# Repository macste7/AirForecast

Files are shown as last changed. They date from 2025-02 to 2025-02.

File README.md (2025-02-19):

<div align="center">
<h1>AirForecast Open Source Project</h1>
</div>

**AirForecast** was designed to collect and visualize air quality data, as well as predict future values using the [Holt-Winters](https://www.pmorgan.com.au/tutorials/holt-winters-method-and-northam-temperature-data/) model. It utilizes **InfluxDB** for data storage and **Grafana** for visualization. Two **RGB LEDs** provide instant AQI feedback without needing a screen. This project was inspired by the increasing frequency of wildfires worldwide. **AirForecast** helps users stay informed about air quality and potential health risks.

## 🚀 Project Features  
- **2 RGB LEDs** – Instant AQI (PM2.5) visualization  
- **Grafana** – Interactive air quality data visualization  
- **InfluxDB** – Stores data for up to **30 days**  
- **Holt-Winters Model** – Predicts future air quality trends  
- **Environmental Sensors** – Measures **PM1.0, PM2.5, PM10, temperature, humidity, and pressure**  

## 📊 **Grafana Dashboard Output**  
<div align="center">
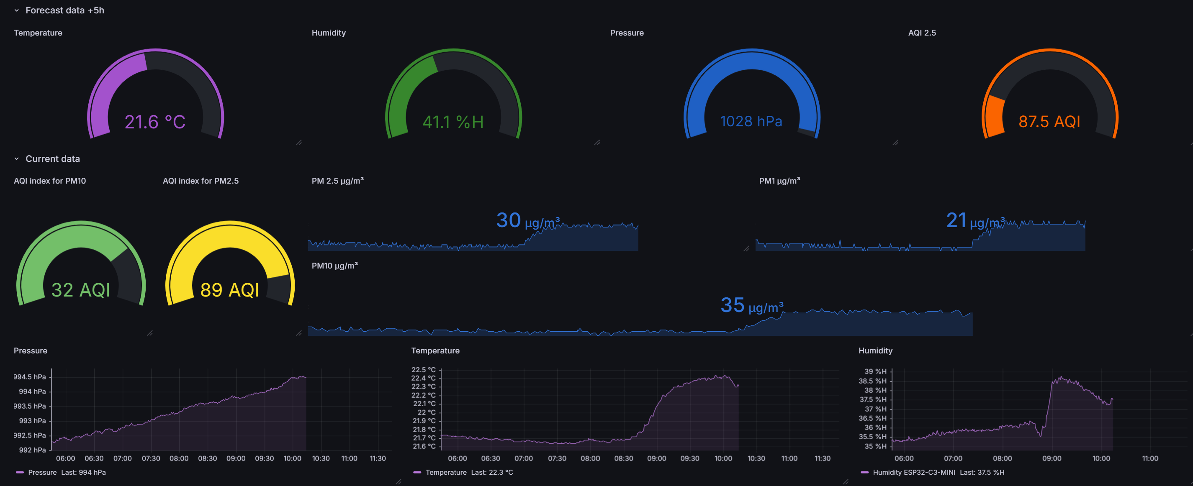
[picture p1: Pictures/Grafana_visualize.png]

</div>

## **AirForecast device**  
<div align="center">
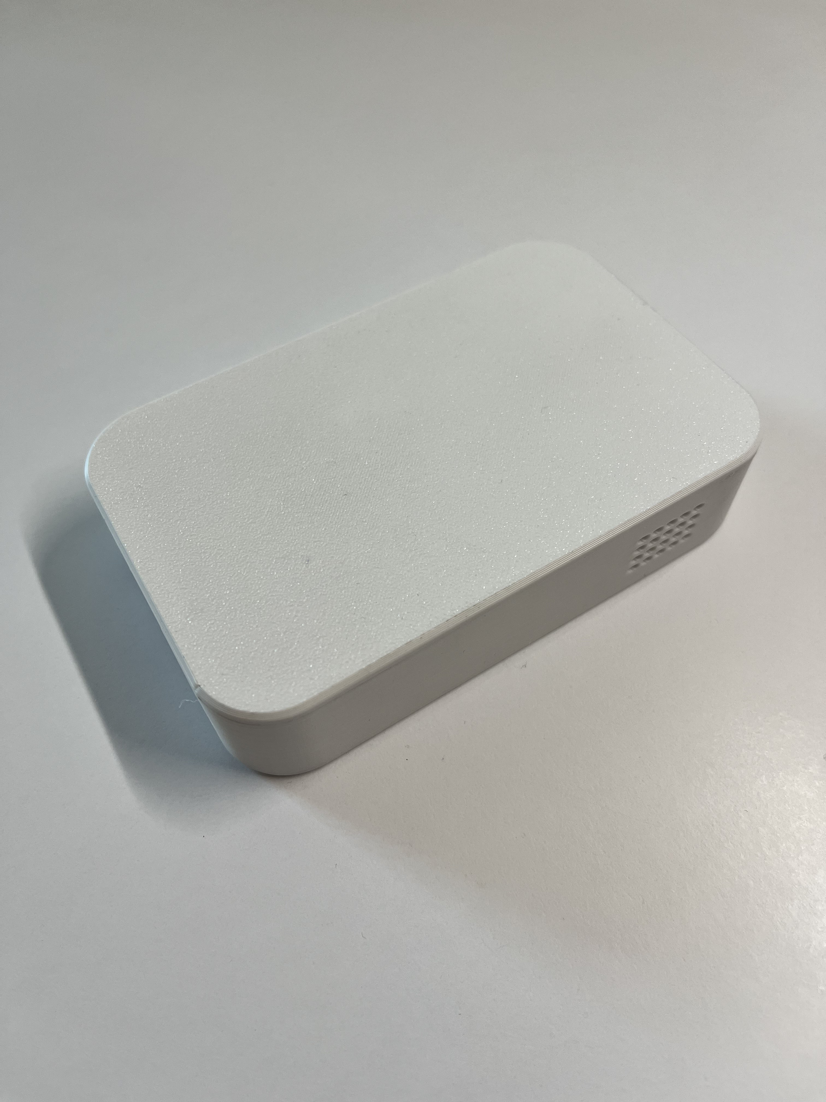
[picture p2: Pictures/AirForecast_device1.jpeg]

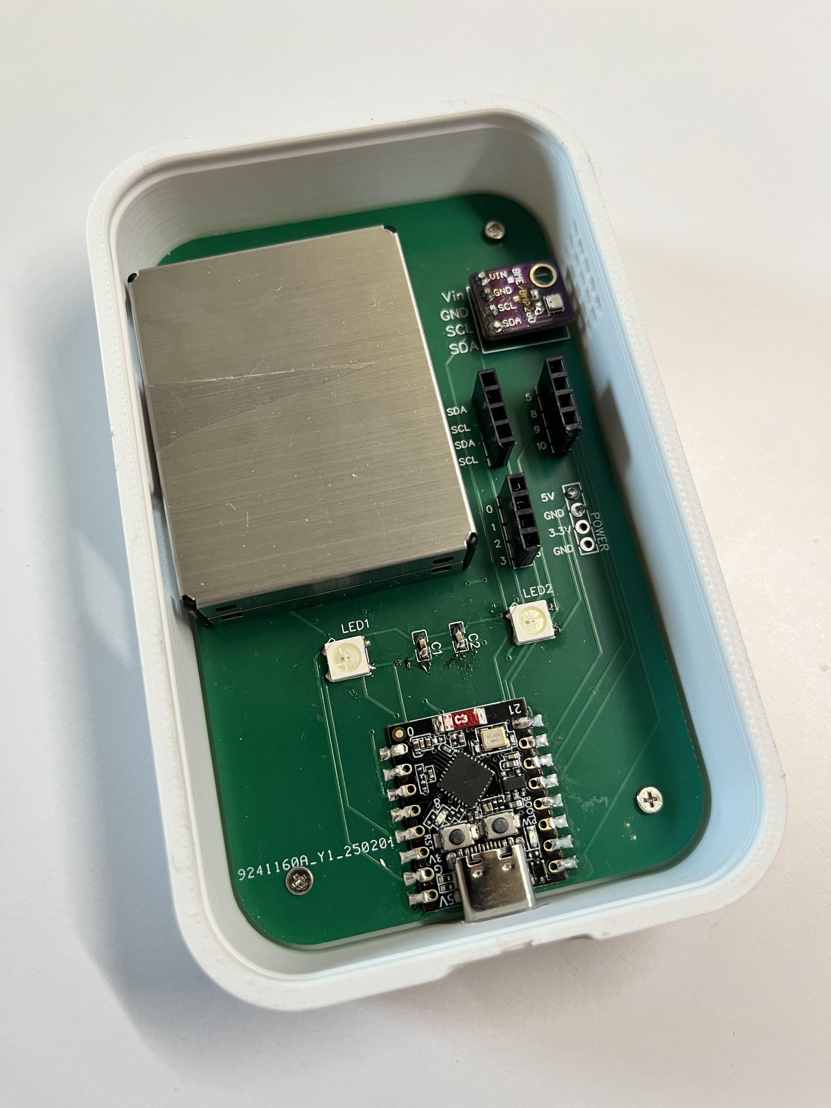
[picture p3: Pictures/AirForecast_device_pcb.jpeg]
  
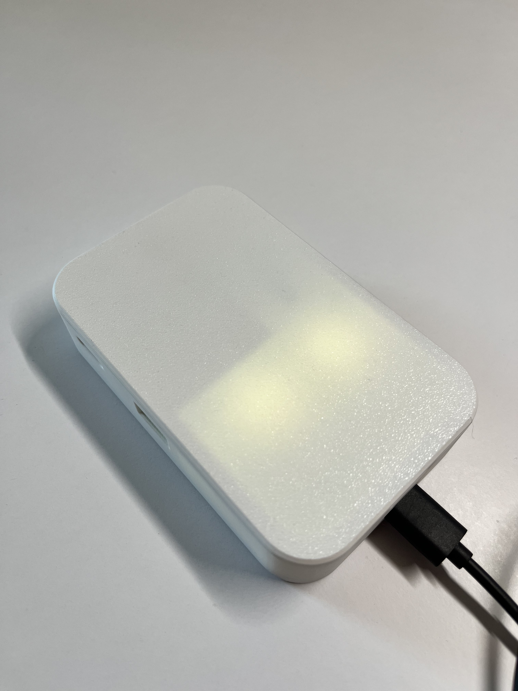
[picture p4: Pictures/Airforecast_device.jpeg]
    

</div>

---
<div align="center">
<h1>How to build this project</h1>
</div>

## 🔧 **Required Components**  
- **ESP32** development board  
- **PMS7003** (PM1.0, PM2.5, PM10 air quality sensor)  
- **BME280** (temperature, humidity, pressure sensor)  
- **2 RGB LEDs** (NeoPixel)  

## ⚡ **Pinout & Wiring**  

| Component  | ESP32 C3 Mini Pins |
|---|---|
| PMS7003 RX | **21** |
| PMS7003 TX | **20** |
| BME280 SDA | **6** |
| BME280 SCL | **7** |
| RGB LED | **4** |

## 📡 **WiFi & InfluxDB Configuration**  

### **1️⃣ Creating a New Bucket**  
Follow these steps to create the **"PMS sensor project"** bucket in **InfluxDB**:

➡️ **Step 1:** Log in to **InfluxDB Cloud** at [https://cloud2.influxdata.com](https://cloud2.influxdata.com)  
➡️ **Step 2:** In the left menu, go to **Load Data** → **Buckets**  
➡️ **Step 3:** Click **+ CREATE BUCKET**  
➡️ **Step 4:** Enter **Bucket Name**: `PMS sensor project`  
➡️ **Step 5:** Set **Retention Period** (e.g., `30 days`)  
➡️ **Step 6:** Click **Create** to save the bucket  

### **2️⃣ Generating an API Token**  
To send data to InfluxDB, you need an **API Token**:

➡️ **Step 1:** In the left menu, go to **Load Data** → **API Tokens**  
➡️ **Step 2:** Click **+ Generate API Token**  
➡️ **Step 3:** Select **All Access Token** or **Custom Token**  
➡️ **Step 4:** (For **Custom Token**) → Give **Read & Write** permissions for your bucket  
➡️ **Step 5:** Click **Generate Token**  
➡️ **Step 6:** Copy and **save** the API Token (you **cannot view it again**!)  

### **3️⃣ Updating Your Configuration and uploading**  
Once you have your **Bucket Name** and **API Token**, update your configuration and upload sketch to ESP32 C3 Mini:

```cpp
#define WIFI_SSID "Your_WiFi_SSID"          // WiFi network name
#define WIFI_PASSWORD "Your_WiFi_Password"  // WiFi password

#define INFLUXDB_URL "http://your-influxdb-server"  // InfluxDB server URL
#define INFLUXDB_TOKEN "your-api-token"             // API Token from InfluxDB
#define INFLUXDB_ORG "your-organization"            // Organization name in InfluxDB
#define INFLUXDB_BUCKET "PMS sensor project"        // Your newly created bucket
```
## 📊 Setting Up Grafana to Fetch Data from InfluxDB  
Adding InfluxDB as a Data Source

➡️ **Step 1:** Open **Grafana** and log in  
➡️ **Step 2:** Click on the ⚙️ **Settings** icon in the left menu  
➡️ **Step 3:** Select **Data Sources**  
➡️ **Step 4:** Click the **+ Add data source** button  
➡️ **Step 5:** Choose **InfluxDB** from the list  

##  Configuring InfluxDB Connection  

###  **Basic Settings**  
- **Name:** `PMS sensor project` *(or any name you prefer)*  
- Select **Flux** (the preferred query language for InfluxDB 2.0)  

###  **HTTP Settings**  
- **URL:** https://us-east-1-1.aws.cloud2.influxdata.com *(This URL may vary depending on your InfluxDB cloud region—check your InfluxDB dashboard.)*
###  **Enable Basic Authentication**  
- Toggle **Basic auth** ✅
###  **Basic Auth Details**  
- **User:** *(Your InfluxDB email, e.g., `your-email@example.com`)*  
- **Password:** *(Use your password for influxdb account)*

###  **InfluxDB Details**  
- **Organization:** *(Your InfluxDB organization)*  
- **Token:** *(Paste the API Token generated from InfluxDB.)*  
##  Dashboards in Grafana
Add flux queries to your dashboard. You can find a queries in the files.
## License
This project is licensed under the **GNU Affero General Public License v3.0 (AGPL-3.0)**.  
See the [LICENSE](LICENSE) file for details.

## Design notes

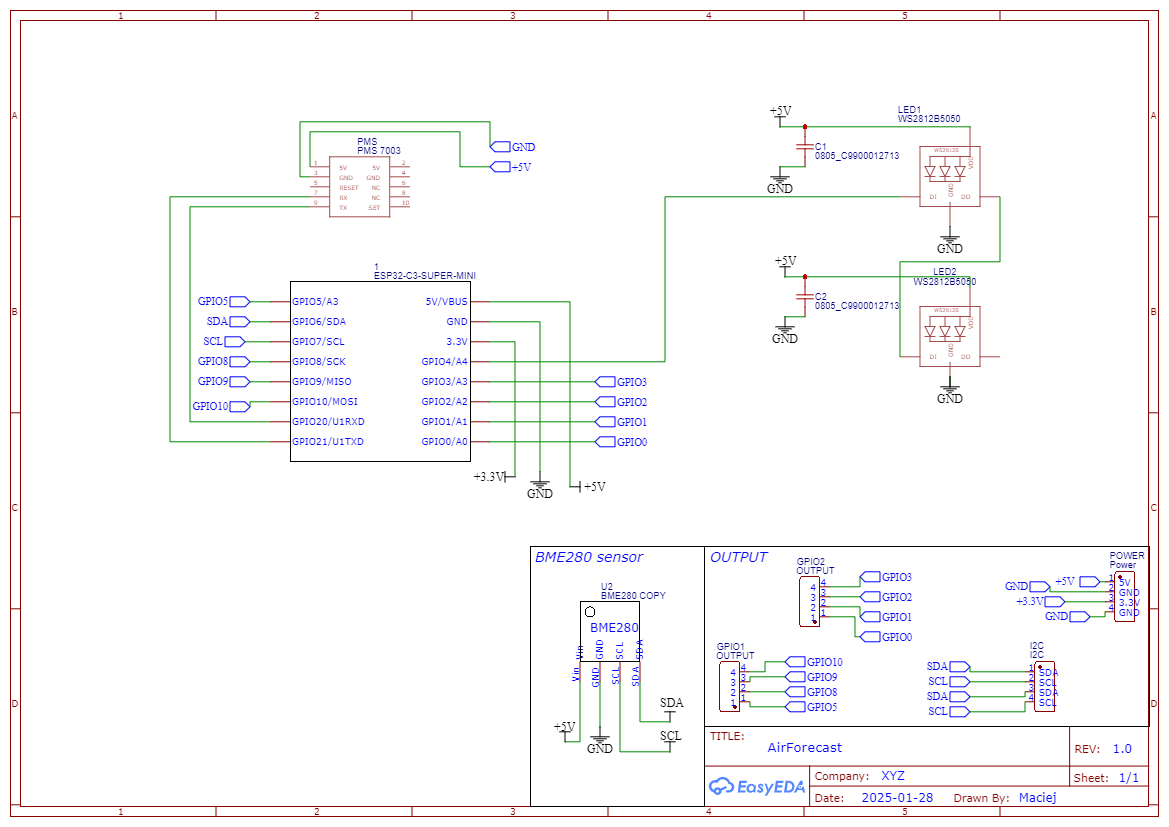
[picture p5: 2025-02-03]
Pictures/Schematic_AirForecastV1.0.png

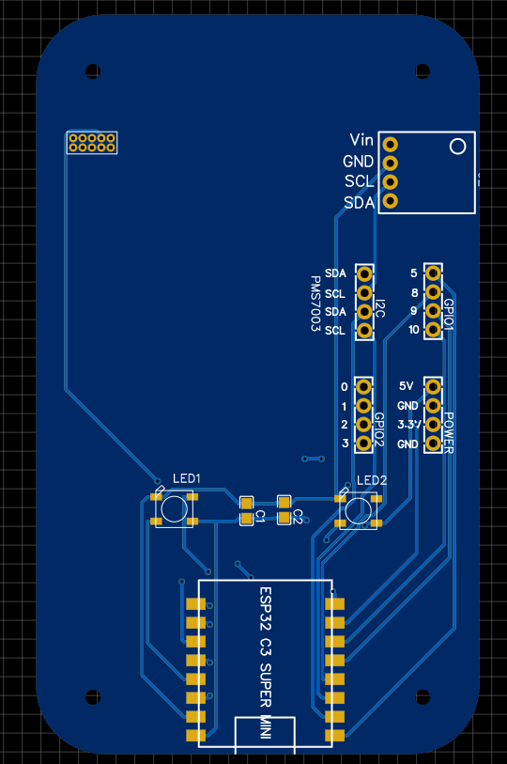
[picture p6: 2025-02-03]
Pictures/PCB_top.png

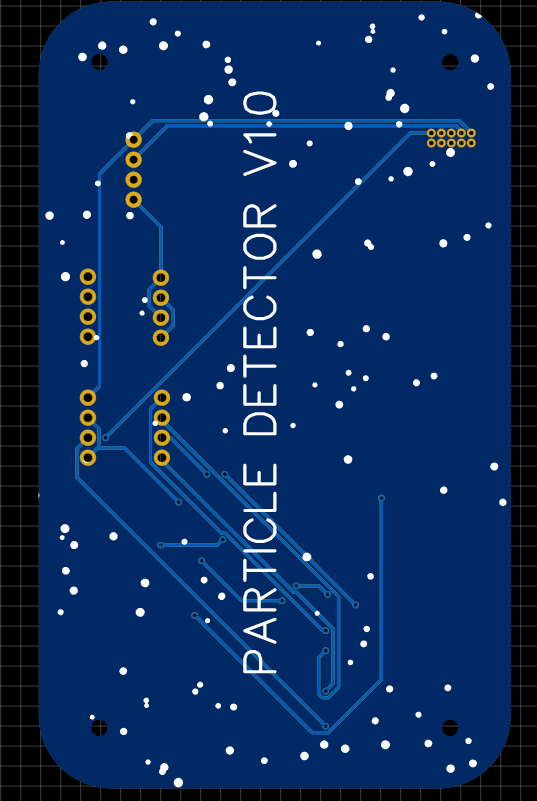
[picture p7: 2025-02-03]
Pictures/PCB_bottom.png

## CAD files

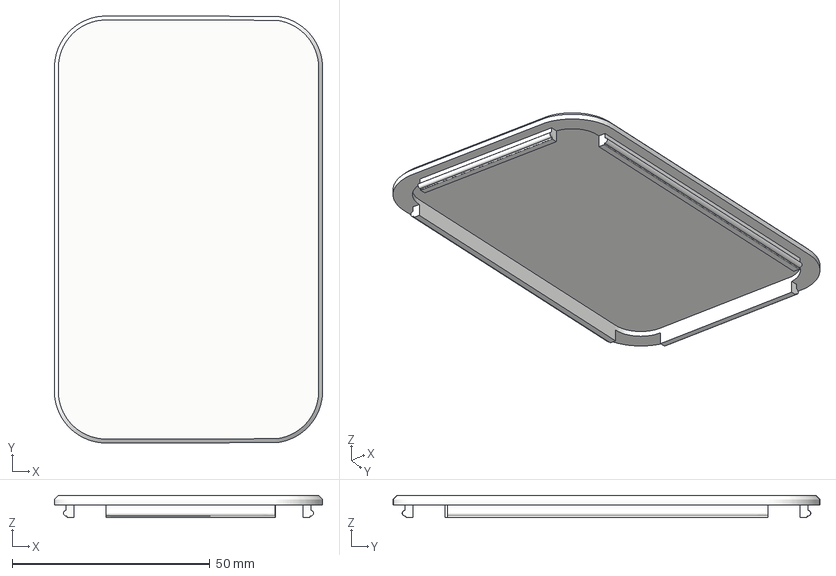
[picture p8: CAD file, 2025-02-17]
3Dmodels/Top_lid_V1.0.3mf
67.9 x 108.1 x 5.60 mm

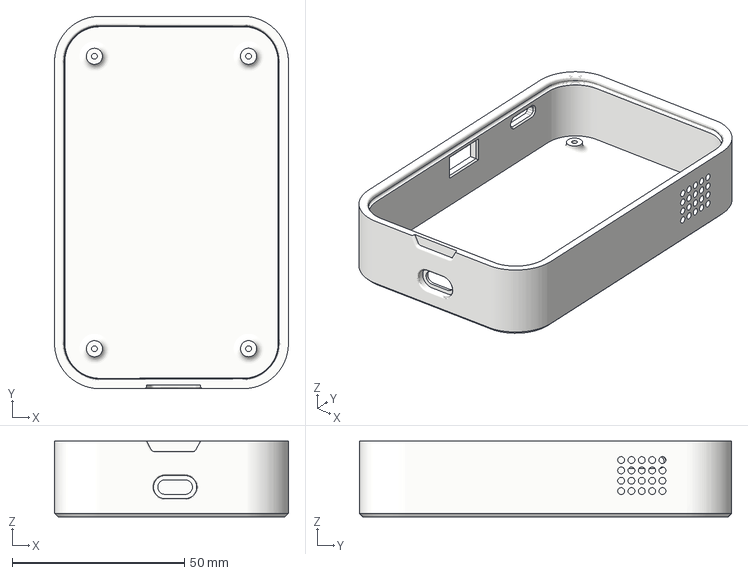
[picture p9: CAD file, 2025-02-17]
3Dmodels/Bottom_case_V1.0.3mf
67.9 x 108.1 x 22.0 mm

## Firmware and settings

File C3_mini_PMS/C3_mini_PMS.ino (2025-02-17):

#include <PMS.h>
#include <Adafruit_NeoPixel.h>
#include <InfluxDbClient.h>
#include <InfluxDbCloud.h>
#include <Wire.h>
#include <WiFi.h>
#include <Adafruit_Sensor.h>
#include <Adafruit_BME280.h>
// =========================== ESP32 PINS ===========================
#define SDA_PIN 6
#define SCL_PIN 7
#define RX_PIN 20     // RX for PMS7003
#define TX_PIN 21     // TX for PMS7003
#define RGB_PIN 4     // RGB LED
#define PIXELS_NUM 2  // Number of RGB leds
// ======================== InfluxDB configuration ======================
#define DEVICE_TYPE "ESP32"
#define WIFI_SSID ""
#define WIFI_PASSWORD ""
//Influx_DB
#define INFLUXDB_URL ""                                              // server address
#define INFLUXDB_TOKEN ""  // Your api key
#define INFLUXDB_ORG ""                                                                            // Organisation ID
#define INFLUXDB_BUCKET "Air_forecast_bucket"                                                                      // Your bucket name
#define TZ_INFO "CET-1CEST,M3.5.0/2,M10.5.0/3"                                                                     // Time-zone
// ======================== Debug ===========================

//Change to 1 to see log messages
#define DEBUG 1
#if DEBUG
#define Debug(x) Serial.print(x);
#define Debugln(x) Serial.println(x);
#else
#define Debugln(x)
#define Debug(x)
#endif
//Change to  1 to see PMS and BME sensor data
#define SHOW_PMS 1
//Turn on or off RGB leds
#define RGB_MODE 1
#define BRIGHTNESS_PERCENT 100 //0-100%
// ======================== Obiekty globalne ======================
Adafruit_BME280 bme;
Adafruit_NeoPixel strip(PIXELS_NUM, RGB_PIN, NEO_GRB + NEO_KHZ800);
InfluxDBClient client(INFLUXDB_URL, INFLUXDB_ORG, INFLUXDB_BUCKET, INFLUXDB_TOKEN, InfluxDbCloud2CACert);
Point sensor("ESP32_weather_station");
HardwareSerial mySerial(0);
PMS pms(mySerial);
PMS::DATA data;

// ======================== Data ======================
struct PMS_data {
  uint16_t PM1 = NULL;
  uint16_t PM25 = NULL;
  uint16_t PM10 = NULL;
};

struct AQI_data {
  int AQI_PM25 = NULL;
  int AQI_PM10 = NULL;
  String AQI_PM25_desc;
};

struct BME280_data {
  float temperature;
  float pressure;
  float humidity;
};

// ======================== Global Variables ======================
PMS_data PMS7003;
AQI_data AQIdata;
BME280_data BMEdata;
static int delay_time = 15;      // Delay in seconds for collecting PMS sensor data
static int send_data_delay = 30;  // Delay in seconds to send data to Influx DB
unsigned long prevMillisreconnect = 0;
unsigned long reconnectTimeout = 15;  // Delay in seconds, timeout for reconnecting
// ======================== Functions ====================
void setRGBleds(uint8_t red, uint8_t green, uint8_t blue, int num_leds) {
  strip.fill(strip.Color(red, green, blue), 0, num_leds);
  strip.show();
}
void RGBAnimation(int num_leds) {
  for (int i = 0; i <= 255; i++) {
    strip.fill(strip.Color(0, 0, i), 0, num_leds);
    strip.show();
    delay(2);
  }
  for (int x = 255; x >= 0; x--) {
    strip.fill(strip.Color(0, 0, x), 0, num_leds);
    strip.show();
    delay(2);
  }
  strip.fill(strip.Color(0, 0, 0), 0, num_leds);
}

void Save_data(PMS_data *pms_data, uint16_t PM1, uint16_t PM25, uint16_t PM10) {
  pms_data->PM1 = PM1;
  pms_data->PM25 = PM25;
  pms_data->PM10 = PM10;
}
void Request_data_BME() {
  BMEdata.humidity = bme.readHumidity();
  BMEdata.pressure = bme.readPressure() / 100.0F;
  BMEdata.temperature = bme.readTemperature();
}
int AQI_algorithm(uint16_t PM, uint16_t Clow, uint16_t Chigh, uint16_t Ilow, uint16_t Ihigh) {
  return int((float(Ihigh - Ilow) / (Chigh - Clow)) * (PM - Clow) + Ilow);
}
int AQI_for_PM25(uint16_t PM25) {
  if (PM25 <= 12) return AQI_algorithm(PM25, 0, 12, 0, 50);
  if (PM25 <= 35) return AQI_algorithm(PM25, 12, 35, 51, 100);
  if (PM25 <= 55) return AQI_algorithm(PM25, 35, 55, 101, 150);
  if (PM25 <= 150) return AQI_algorithm(PM25, 55, 150, 151, 200);
  if (PM25 <= 250) return AQI_algorithm(PM25, 150, 250, 201, 300);
  if (PM25 <= 350) return AQI_algorithm(PM25, 250, 350, 301, 400);
  if (PM25 <= 500) return AQI_algorithm(PM25, 350, 500, 401, 500);
  return 500;
}

int AQI_for_PM10(uint16_t PM10) {
  if (PM10 <= 54) return AQI_algorithm(PM10, 0, 54, 0, 50);
  if (PM10 <= 154) return AQI_algorithm(PM10, 54, 154, 51, 100);
  if (PM10 <= 254) return AQI_algorithm(PM10, 154, 254, 101, 150);
  if (PM10 <= 354) return AQI_algorithm(PM10, 254, 354, 151, 200);
  if (PM10 <= 424) return AQI_algorithm(PM10, 354, 424, 201, 300);
  if (PM10 <= 504) return AQI_algorithm(PM10, 424, 504, 301, 400);
  if (PM10 <= 604) return AQI_algorithm(PM10, 504, 604, 401, 500);
  return 500;
}
void DisplayAQIColor(int AQI_value) {
  if (AQI_value <= 50) {
    setRGBleds(0, 255, 0, PIXELS_NUM);  //Green
  } else if (AQI_value <= 100) {
    setRGBleds(255, 255, 0, PIXELS_NUM);  //Yellow
  } else if (AQI_value <= 150) {
    setRGBleds(255, 165, 0, PIXELS_NUM);  //Orange
  } else if (AQI_value <= 200) {
    setRGBleds(255, 0, 0, PIXELS_NUM);  //Red
  } else if (AQI_value <= 300) {
    setRGBleds(128, 0, 128, PIXELS_NUM);  //Violet
  } else {
    setRGBleds(255, 255, 255, PIXELS_NUM);  // White
  }
}
void Show_data_PMS(PMS_data data) {
  Serial.println("====== POMIARY ======");
  Serial.print("AQI PM2.5: ");
  Serial.print(AQI_for_PM25(data.PM25));
  Serial.print(" | AQI PM10: ");
  Serial.println(AQI_for_PM10(data.PM10));
  Serial.print("PM1.0: ");
  Serial.print(data.PM1);
  Serial.print(" µg/m³ | PM2.5: ");
  Serial.print(data.PM25);
  Serial.print(" µg/m³ | PM10: ");
  Serial.println(data.PM10);
  Serial.print("T: ");
  Serial.print(BMEdata.temperature);
  Serial.print(" *c | H: ");
  Serial.print(BMEdata.humidity);
  Serial.print(" % | P: ");
  Serial.print(BMEdata.pressure);
  Serial.println(" hPa");
  Serial.print("=====================");
}
//This function is called with specified interval using FreeRTOS
void Request_data_PMS() {
  bool success = false;
  pms.requestRead();
  unsigned long StartTime = millis();
  while (!success && (millis() - StartTime < 5000)) {
    success = pms.readUntil(data);
  }
  if (success) {
    Save_data(&PMS7003, data.PM_AE_UG_1_0, data.PM_AE_UG_2_5, data.PM_AE_UG_10_0);
    if (PMS7003.PM25 > 0 && PMS7003.PM10 > 0) {
      AQIdata.AQI_PM25 = AQI_for_PM25(PMS7003.PM25);
      AQIdata.AQI_PM10 = AQI_for_PM10(PMS7003.PM10);
#if RGB_MODE
      DisplayAQIColor(AQIdata.AQI_PM25);
#endif
#if SHOW_PMS
      Show_data_PMS(PMS7003);
#endif
    }
  } else {
    Debugln("Can't retrieve data from PMS sensor, check it!");
  }
}
void PMS_Task(void *pvParameters) {
  const int delay_time = *(int *)pvParameters;
  while (true) {
    Request_data_BME();  // BME280
    Request_data_PMS();
    vTaskDelay(pdMS_TO_TICKS(delay_time * 1000));
  }
}
void setup() {
  Serial.begin(115200);
  mySerial.begin(9600, SERIAL_8N1, RX_PIN, TX_PIN);
  Wire.begin(SDA_PIN, SCL_PIN);
  bme.begin(0x76);
  strip.begin();
  strip.show();
  strip.setBrightness(BRIGHTNESS_PERCENT);
  strip.fill(strip.Color(0, 0, 0), 0, PIXELS_NUM);
  xTaskCreate(PMS_Task, "PMS Task", 2048, &delay_time, 2, NULL);
  RGBAnimation(PIXELS_NUM);
  WiFi.disconnect();
  WiFi.mode(WIFI_STA);
  WiFi.begin(WIFI_SSID, WIFI_PASSWORD);
  Debugln("Connecting to WiFi.");
  while (WiFi.status() != WL_CONNECTED) {
    Debug('.');
    delay(500);
  }
  Debug("\n Connected. IP address:");
  Debugln(WiFi.localIP());
  Debug("RSSI:");
  Debugln(WiFi.RSSI());
  sensor.addTag("Device_info", DEVICE_TYPE);
  timeSync(TZ_INFO, "pool.ntp.org", "time.nis.gov");
  if (client.validateConnection()) {
    Debug("Connected to InfluxDB: ");
    Debugln(client.getServerUrl());
  } else {
    Debug("InfluxDB connection failed: ");
    Debugln(client.getLastErrorMessage());
  }
}
void loop() {
  if (WiFi.status() != WL_CONNECTED) {
    Debugln("Wifi connection lost..");
    unsigned long reconnectMillis = millis();
    if (reconnectMillis - prevMillisreconnect >= reconnectTimeout * 1000) {
      prevMillisreconnect = reconnectMillis;
      WiFi.disconnect();
      WiFi.reconnect();
      Debugln("Reconnecting...");
    }
  } else {
    //If connected send data
    sensor.clearFields();
    sensor.addField("PM 1", PMS7003.PM1);
    sensor.addField("PM 25", PMS7003.PM25);
    sensor.addField("PM 10", PMS7003.PM10);
    sensor.addField("AQI index for PM 25", AQIdata.AQI_PM25);
    sensor.addField("AQI index for PM 10", AQIdata.AQI_PM10);
    sensor.addField("Temperature", BMEdata.temperature);
    sensor.addField("Humidity", BMEdata.humidity);
    sensor.addField("Pressure", BMEdata.pressure);
    if (!client.writePoint(sensor)) {
      Debug("InfluxDB write failed: ");
      Debugln(client.getLastErrorMessage());
    } else {
      Debugln("Data sent to InfluxDB");
    }
  }
  delay(send_data_delay * 1000);
}

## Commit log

2025-02-03 Airforecast schematic
2025-02-17 3D models
    [Bottom_case_V1.0.3mf, Top_lid_V1.0.3mf]
